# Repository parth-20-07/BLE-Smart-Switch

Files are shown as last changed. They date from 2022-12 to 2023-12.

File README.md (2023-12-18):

<!-- omit from toc -->
# BLE Smart Switch

**Table of Contents**

- [Why BLE Smart Switch is needed?](#why-ble-smart-switch-is-needed)
- [Features of our Smart Switch](#features-of-our-smart-switch)
- [How to use the device](#how-to-use-the-device)
- [Schematic Design](#schematic-design)
- [PCB Design](#pcb-design)
- [Rendered Images](#rendered-images)
- [Design Details](#design-details)

# Why BLE Smart Switch is needed?

The BLE Smart Switch provides convenient control over electrical sockets through Bluetooth technology. It enables users to manage home appliances remotely, ensuring energy efficiency and enhanced home automation.

# Features of our Smart Switch

- Control up to 2 sockets remotely.
- Schedule socket activation/deactivation.
- Real-time monitoring and control through a BLE app.
- Easy-to-use interface for hassle-free operation.
- Compact and modern design, suitable for various environments.

# How to use the device

1. Connect the device to the sockets you wish to control.
2. Pair the device with the BLE app.
3. Use the app to set schedules or control sockets manually.

# Schematic Design

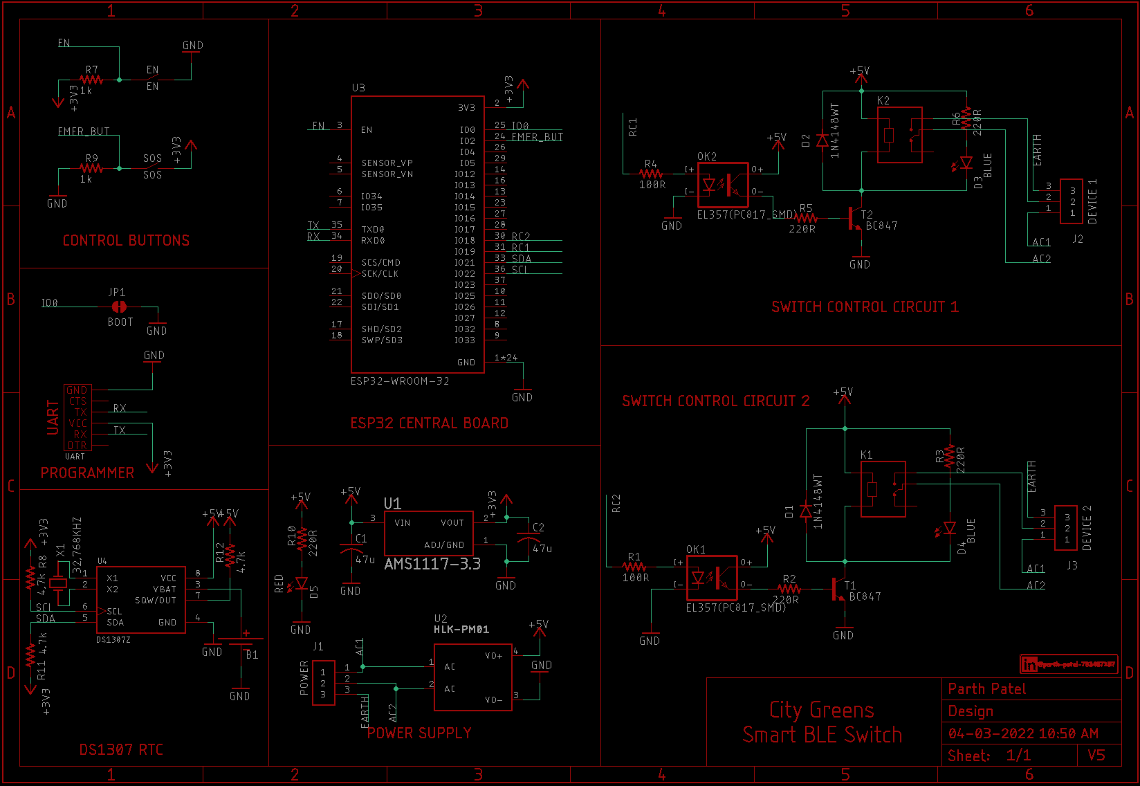
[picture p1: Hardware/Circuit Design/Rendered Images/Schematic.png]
schematic-1


# PCB Design

**Top View**

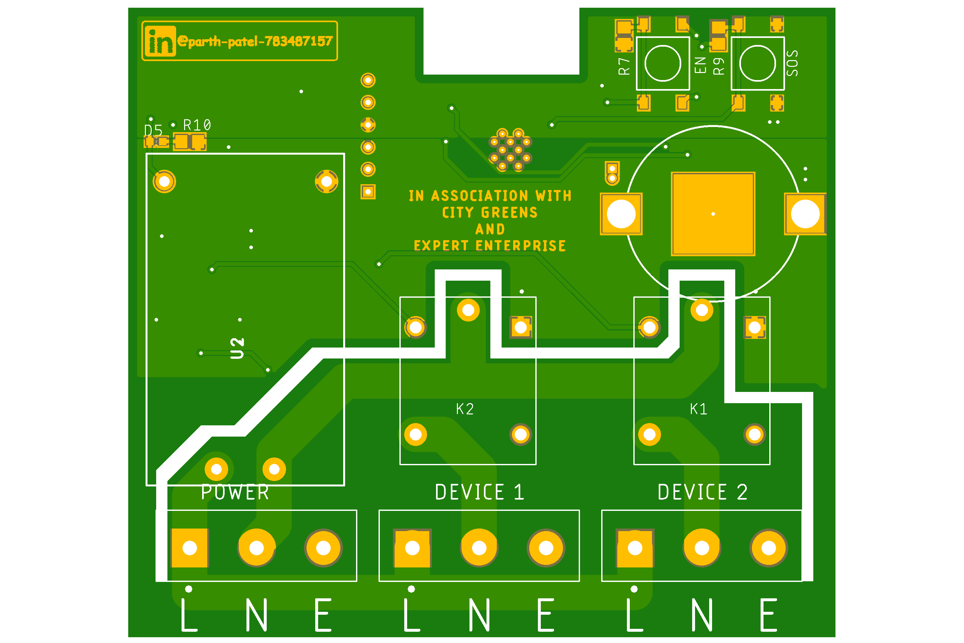
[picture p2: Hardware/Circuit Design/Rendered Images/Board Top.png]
pcb-top


**Bottom View**

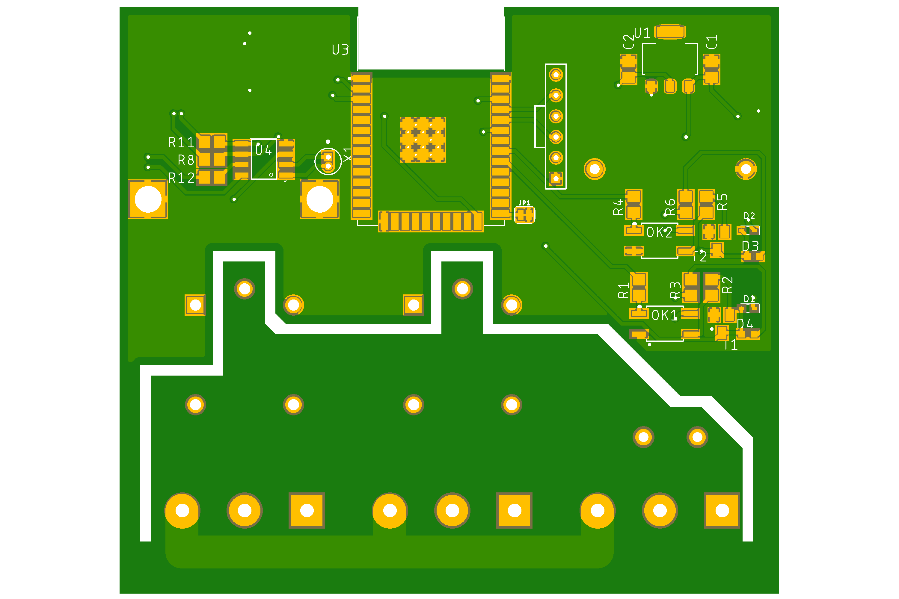
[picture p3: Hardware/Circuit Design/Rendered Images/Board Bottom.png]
pcb-bottom


# Rendered Images

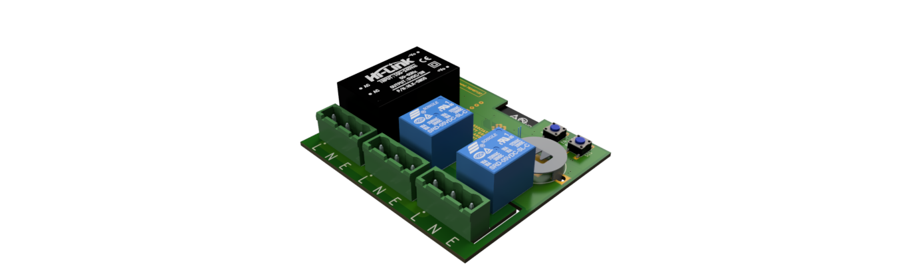
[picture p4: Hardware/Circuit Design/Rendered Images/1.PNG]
render-1


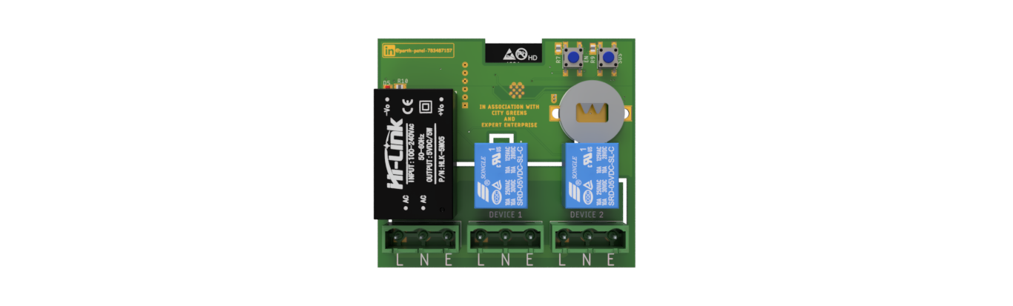
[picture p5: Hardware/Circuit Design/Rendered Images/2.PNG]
render-2


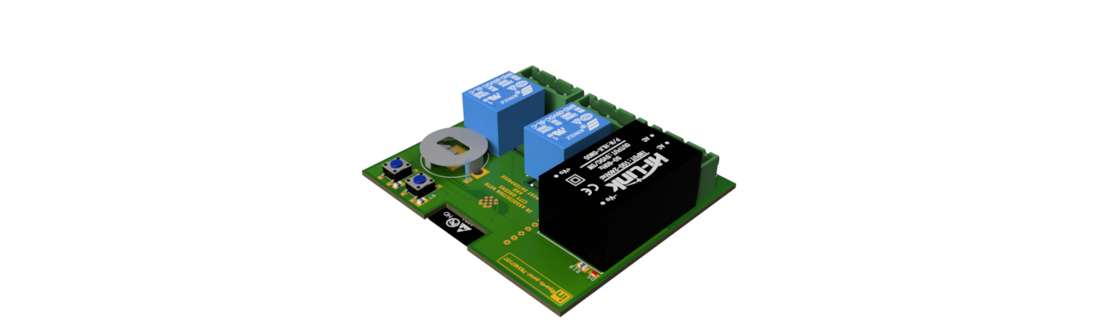
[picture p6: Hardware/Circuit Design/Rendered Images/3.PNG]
render-3


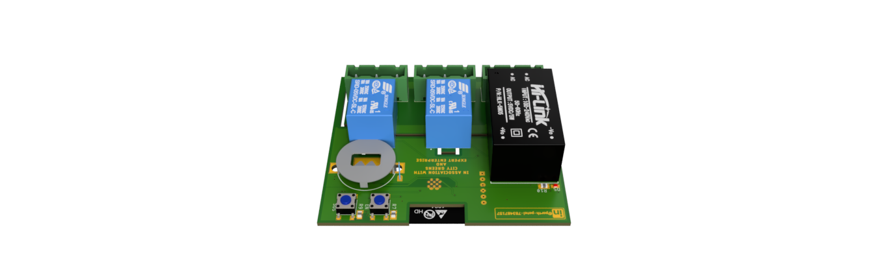
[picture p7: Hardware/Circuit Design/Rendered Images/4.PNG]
render-4


# Design Details

- Designed for: Ecologic Private Ltd.
- Designed by: [Parth Patel](mailto:parth.pmech@gmail.com)

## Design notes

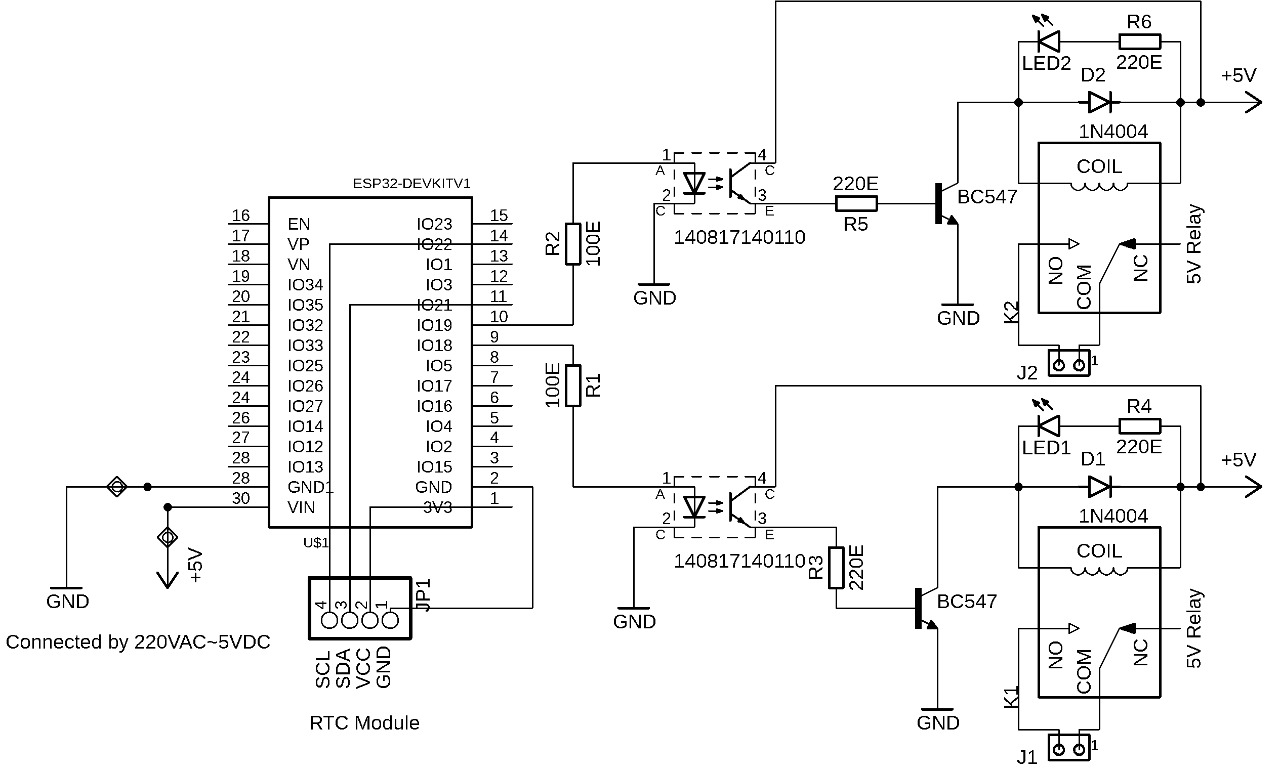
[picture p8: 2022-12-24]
Resources/Schematic Reference.jpg

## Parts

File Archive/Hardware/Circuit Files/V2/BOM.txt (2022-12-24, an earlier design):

TACTILE_SWITCH_SMD_4.5MM (Version 1): https://www.sunrom.com/p/smd-tactile-switch-45x45x38mm
0805 RESISTORS: https://www.sunrom.com/c/resistors?s_47%5B%5D=0805+%282012+metric%29
AMS1117-3.3: https://www.sunrom.com/p/ams1117-33-sot223
FUSE: https://www.sunrom.com/p/t63a-250v-rectangular-fuse
OPTOCOUPLER: https://www.sunrom.com/p/pc817-low-voltage-high-density-optocoupler
NPN: https://www.sunrom.com/p/bc847-npn-45v-100ma-sot23
Diode: https://www.sunrom.com/p/1n4148---1n4148wt---smd---sod523-0603
RED LED: https://www.sunrom.com/p/red-smd-led-0603
BLUE LED: https://www.sunrom.com/p/blue-smd-led-0603

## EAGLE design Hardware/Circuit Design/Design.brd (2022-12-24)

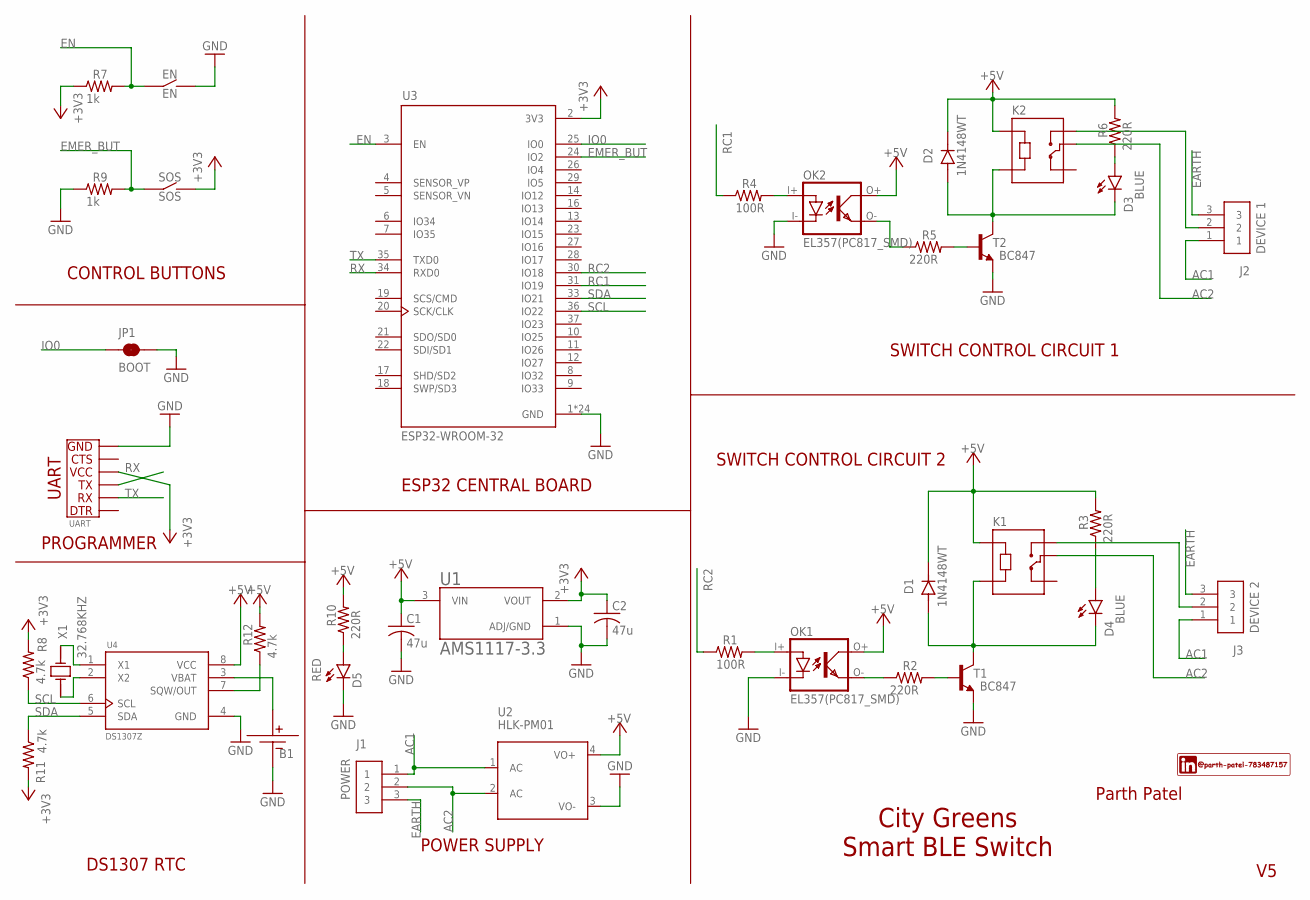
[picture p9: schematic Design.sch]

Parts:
B1: CR3032-METAL; CR2032-METAL
C1, C2: 47u; C0805
D1, D2: 1N4148WT; SODFL1608X70N
D3, D4: BLUE; CHIP-LED0603
D5: RED; CHIP-LED0603
EN: EN; SMD-4.5X4.5-TACTILE-PUSH-BUTTON
J1: POWER; TERMINALBLOCK_PLUGGABLE-3-7.62MM
J2: DEVICE 1; TERMINALBLOCK_PLUGGABLE-3-7.62MM
J3: DEVICE 2; TERMINALBLOCK_PLUGGABLE-3-7.62MM
JP1: BOOT; SMT-JUMPER_2_NC_TRACE_SILK
K1, K2: SRD-05VDC-SL-C; RELAY_SRD-05VDC-SL-C
OK1, OK2: EL357(PC817_SMD); SOP254P715X240-4N
R1, R4: 100R; R0805
R2, R3, R5, R6, R10: 220R; R0805
R7, R9: 1k; R0805
R8, R11, R12: 4.7k; R0805
SOS: SOS; SMD-4.5X4.5-TACTILE-PUSH-BUTTON
T1, T2: BC847; SOT23
U1: AMS1117-3.3; SOT229P700X180-4N
U2: HLK-PM01
U3: ESP32-WROOM-32; MODULE_ESP32-WROOM-32
U4: DS1307Z; SOIC127P600X175-8N
UART: UART
X1: 32.768KHZ; XTAL_AB38T-32.768KHZ

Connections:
+3V3: C2.1, R7.1, R8.2, R11.2, SOS.2.1 (S2), SOS.2.2 (S2), U1.2 (VOUT), U3.2 (3V3), UART.VCC
+5V: C1.1, D1.D+, D2.D+, K1.A1, K2.A1, OK1.O+, OK2.O+, R3.2, R6.2, R10.2, R12.2, U1.3 (VIN), U2.4 (VO+), U4.8 (VCC)
AC1: J1.1, J2.1, J3.1, U2.1 (AC)
AC2: J1.2, K1.COM, K2.COM, U2.2 (AC)
EARTH: J1.3, J2.3, J3.3
EMER_BUT: R9.2, SOS.1.1 (S1), SOS.1.2 (S1), U3.24 (IO2)
EN: EN.1.1 (S1), EN.1.2 (S1), R7.2, U3.3 (EN)
GND: B1.-VE1 (-VE), B1.-VE2 (-VE), C1.2, C2.2, D5.C, EN.2.1 (S2), EN.2.2 (S2), JP1.2, OK1.I-, OK2.I-, R9.1, T1.2 (E), T2.2 (E), U1.1 (ADJ/GND), U2.3 (VO-), U3.1 (GND), U3.15 (GND), U3.38 (GND), U3.39_1 (GND), U3.39_2 (GND), U3.39_3 (GND), U3.39_4 (GND), U3.39_5 (GND), U3.39_6 (GND), U3.39_7 (GND), U3.39_8 (GND), U3.39_9 (GND), U3.39_10 (GND), U3.39_11 (GND), U3.39_12 (GND), U3.39_13 (GND), U3.39_14 (GND), U3.39_15 (GND), U3.39_16 (GND), U3.39_17 (GND), U3.39_18 (GND), U3.39_19 (GND), U3.39_20 (GND), U3.39_21 (GND), U4.4 (GND), UART.GND
IO0: JP1.1, U3.25 (IO0)
unnamed: B1.+VE, U4.3 (VBAT)
unnamed: OK1.O-, R2.1
unnamed: OK1.I+, R1.2
unnamed: R2.2, T1.1 (B)
unnamed: R12.1, U4.7 (SQW/OUT)
unnamed: D1.D-, D4.C, K1.A2, T1.3 (C)
unnamed: D4.A, R3.1
unnamed: J3.2, K1.NO
unnamed: OK2.I+, R4.2
unnamed: OK2.O-, R5.1
unnamed: R5.2, T2.1 (B)
unnamed: D2.D-, D3.C, K2.A2, T2.3 (C)
unnamed: D3.A, R6.1
unnamed: U4.2 (X2), X1.1
unnamed: J2.2, K2.NO
unnamed: U4.1 (X1), X1.2
unnamed: D5.A, R10.1
RC1: R4.1, U3.31 (IO19)
RC2: R1.1, U3.30 (IO18)
RX: U3.34 (RXD0), UART.TX
SCL: R8.1, U3.36 (IO22), U4.6 (SCL)
SDA: R11.1, U3.33 (IO21), U4.5 (SDA)
TX: U3.35 (TXD0), UART.RX

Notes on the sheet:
City Greens Smart BLE Switch
Parth Patel
ESP32 CENTRAL BOARD
DS1307 RTC
POWER SUPPLY
SWITCH CONTROL CIRCUIT 1
SWITCH CONTROL CIRCUIT 2
CONTROL BUTTONS
PROGRAMMER

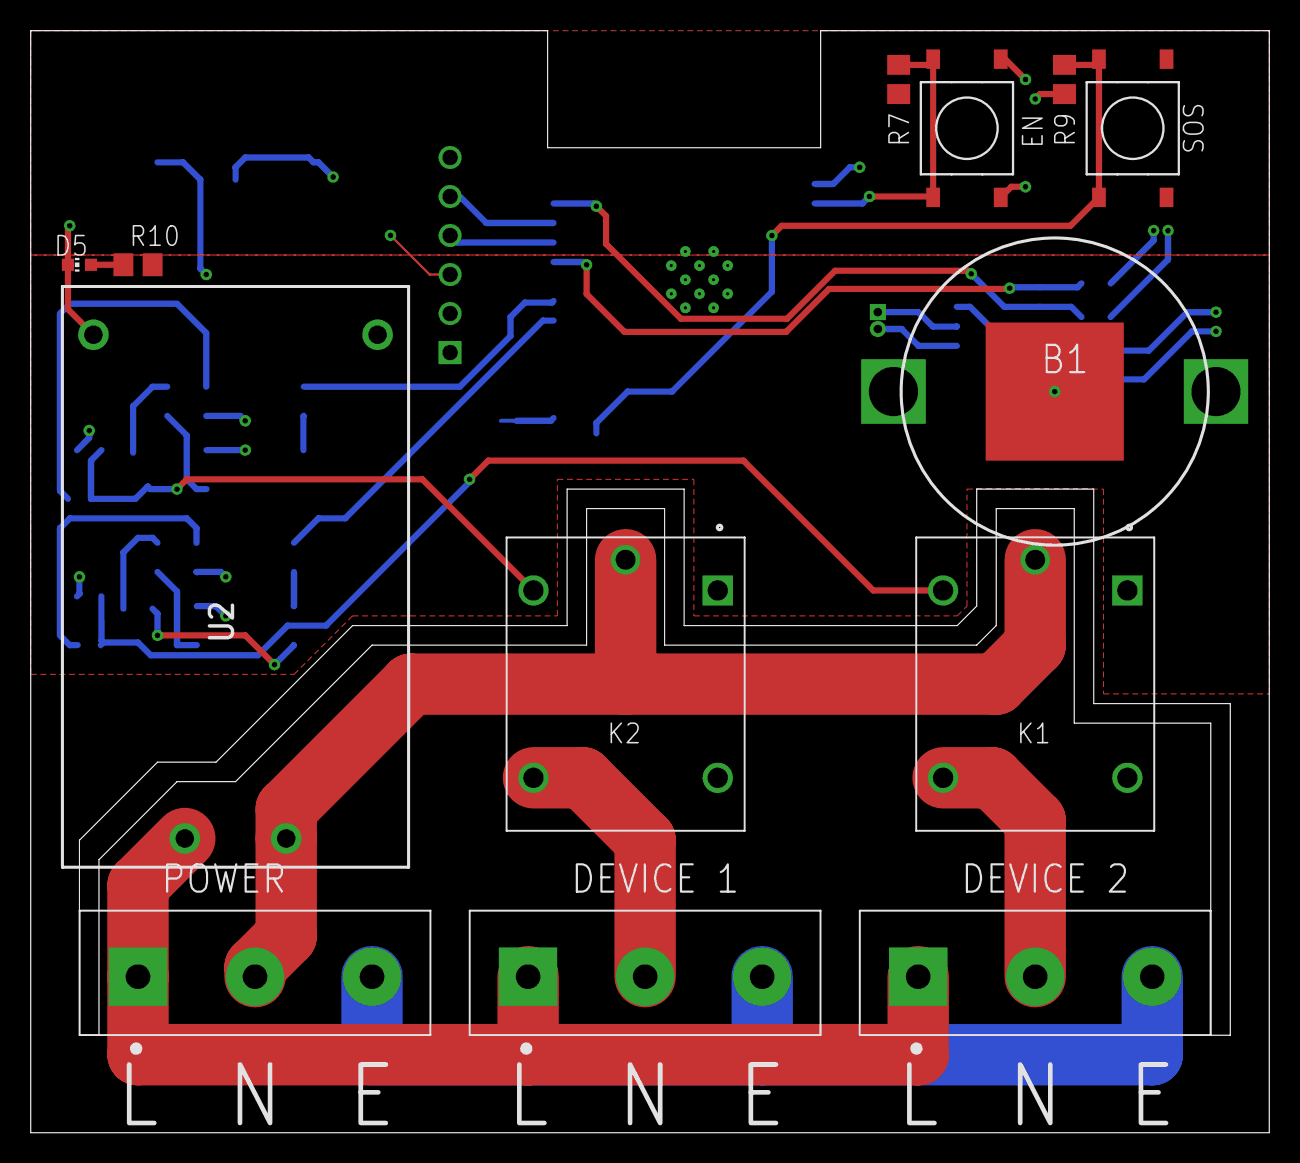
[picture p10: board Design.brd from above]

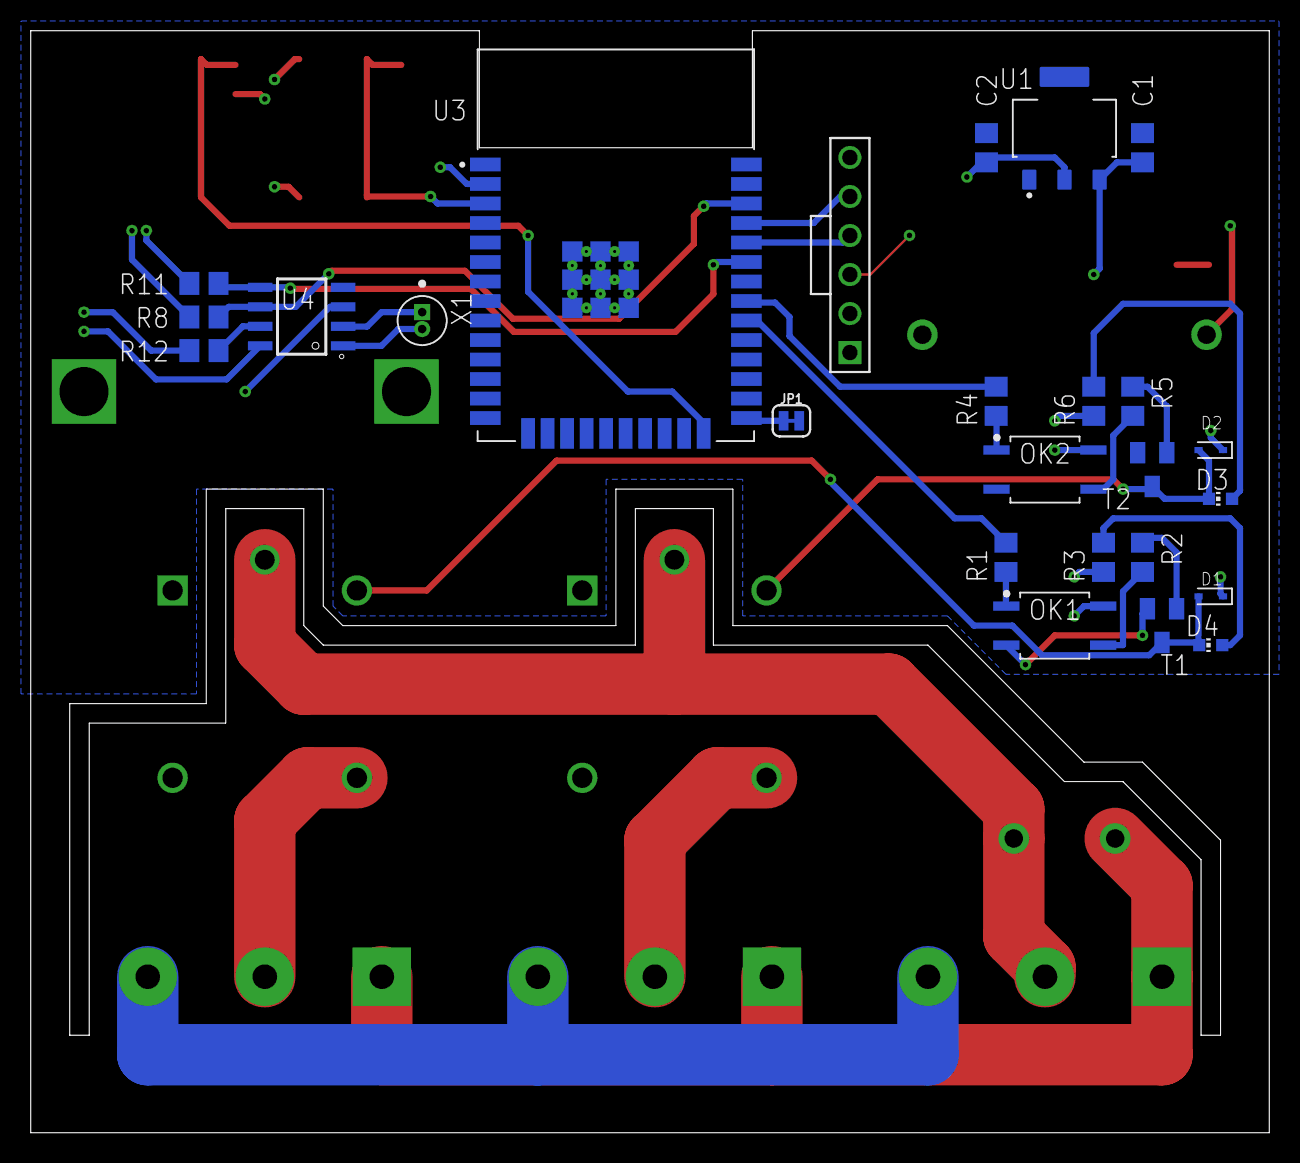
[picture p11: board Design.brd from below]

Board: 2 copper layers, 80.6 x 71.8 mm, 38 parts (25 on the bottom side), 32 nets.

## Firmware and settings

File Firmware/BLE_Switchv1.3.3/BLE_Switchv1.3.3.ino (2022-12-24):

#include <Arduino.h>
#include <nvs_flash.h>

#include "soc/timer_group_struct.h"
#include "soc/timer_group_reg.h"

#define PIN_SCL 22
#define PIN_SDA 21
//-----------------Flags to control state of interfaces for various switching mode-------------
bool app1Flg = true;
bool app2Flg = true;
bool sosFlag = false;
bool tFlag = false; // Flag to indicate Switch Mode command
bool prev_tFlag = false;
bool app1State;
bool app2State;
bool autoMode;
//---------------------------Data Point Storage Variables--------------------------------------
const char *path = "/switchData.txt";
char timeStamp[17];
char msg[23];
int tBytes = 0;
int uBytes = 0;
bool wFlag = false;
unsigned int dCount = 0;
//-----------------------------Variables for Switch Mode---------------------------------------
unsigned int min1 = 0; // Count minutes needed to periodically switch interface 1
unsigned int min2 = 0; // Count minutes needed to periodically switch interface 2
uint8_t rmin = 0;      // Minute variable needed for Timeframe switch mode operation
uint8_t rhr = 0;       // Hour variable needed for Timeframe switch mode operation

bool week[7] = {false, false, false, false, false, false, false};
byte cur_day = 7;
byte curr_zone = 5, prev_zone = 0;
bool zoneChg = false;
unsigned int app1ON, app1OFF, app2ON, app2OFF;
char sch_buff[3];
byte sch;
byte frame_App1[18][4];
byte frame_App2[18][4];
char rtcDay[7][10] = {"Sunday", "Monday", "Tuesday", "Wednesday", "Thursday", "Friday", "Saturday"};
byte App1Sch;
byte App2Sch;
byte b = 0;
byte diff = 0;

void defaultState()
{
  // Configure the Prescaler at 80 the quarter of the ESP32 is cadence at 80Mhz
  // 80000000 / 80 = 1000000 tics / seconde
  timer = timerBegin(0, 80, true); // true - count up; false - count down
  timerAttachInterrupt(timer, &onTime, true);
  timerAlarmWrite(timer, 60 * 1000000, true);
  timerAlarmDisable(timer);

  tFlag = false;
  pref.putBool("prev_tFlag", false);

  smode = 'M';
  initFlg = false;

  app[0].ID[0] = '0';
  app[0].ID[1] = '1';
  app[0].ID[2] = NULL;
  app[1].ID[0] = '0';
  app[1].ID[1] = '2';
  app[1].ID[2] = NULL;

  app[0].prev_state = 0;
  app[0].curr_state = 0;
  app[1].prev_state = 0;
  app[1].curr_state = 0;

  app[0].val[0].mData = 0;
  app[1].val[0].mData = 0;

  for (int k = 0; k < 4; k++)
  {
    app[0].val[k].onMin = 0;
    app[0].val[k].offMin = 0;
    app[1].val[k].onMin = 0;
    app[1].val[k].offMin = 0;
  }

  for (i = 0; i < 4; i++)
  {
    app[0].val[0].tON[i] = 0;
    app[1].val[0].tON[i] = 0;
  }

  for (i = 0; i < 18; i++)
  {
    for (int k = 0; k < 4; k++)
    {
      frame_App1[i][k] = 0;
      frame_App2[i][k] = 0;
    }
  }
  sch = 0;
  App1Sch = 0;
  App2Sch = 0;
  prev_zone = 0;
  autoMode = 0;
  zoneChg = false;

  // Timeframe
  for (i = 0; i < 7; i++)
    week[i] = 0;
  App1Sch = 0;
  App2Sch = 0;
  for (i = 0; i < 18; i++)
  {
    for (int j = 0; j < 4; j++)
      frame_App1[i][j] = 0;
  }

  for (i = 0; i < 18; i++)
  {
    for (int j = 0; j < 4; j++)
      frame_App2[i][j] = 0;
  }
  writeFile("Dy/M/Y,H:M,App1,App2\r\n");
}

void savedData()
{
  // Configure the Prescaler at 80 the quarter of the ESP32 is cadence at 80Mhz
  // 80000000 / 80 = 1000000 tics / seconde
  timer = timerBegin(0, 80, true); // true - count up; false - count down
  timerAttachInterrupt(timer, &onTime, true);
  timerAlarmWrite(timer, 60 * 1000000, true); // 1 minute Timer
  timerAlarmDisable(timer);

  smode = pref.getChar("mode", 0);

  app[0].ID[0] = '0';
  app[0].ID[1] = '1';
  app[0].ID[2] = NULL;
  app[1].ID[0] = '0';
  app[1].ID[1] = '2';
  app[1].ID[2] = NULL;

  app[0].prev_state = pref.getBool("pState1", 0);
  app[0].curr_state = 0;
  app[1].prev_state = pref.getBool("pState2", 0);
  app[1].curr_state = 0;
  // Manual Mode
  app[0].val[0].mData = pref.getBool("man1", 0);
  app[1].val[0].mData = pref.getBool("man2", 0);
  // Period Mode
  app[0].val[0].onMin = pref.getInt("z1A1ON", 0);
  app[0].val[0].offMin = pref.getInt("z1A1OFF", 0);
  app[0].val[1].onMin = pref.getInt("z2A1ON", 0);
  app[0].val[1].offMin = pref.getInt("z2A1OFF", 0);
  app[0].val[2].onMin = pref.getInt("z3A1ON", 0);
  app[0].val[2].offMin = pref.getInt("z3A1OFF", 0);
  app[0].val[3].onMin = pref.getInt("z4A1ON", 0);
  app[0].val[3].offMin = pref.getInt("z4A1OFF", 0);

  app[1].val[0].onMin = pref.getInt("z1A2ON", 0);
  app[1].val[0].offMin = pref.getInt("z1A2OFF", 0);
  app[1].val[1].onMin = pref.getInt("z2A2ON", 0);
  app[1].val[1].offMin = pref.getInt("z2A2OFF", 0);
  app[1].val[2].onMin = pref.getInt("z3A2ON", 0);
  app[1].val[2].offMin = pref.getInt("z3A2OFF", 0);
  app[1].val[3].onMin = pref.getInt("z4A2ON", 0);
  app[1].val[3].offMin = pref.getInt("z4A2OFF", 0);

  min1 = pref.getUInt("m1", 0);
  min2 = pref.getUInt("m2", 0);

  // Timeframe
  pref.getBytes("Week", week, 7);
  App1Sch = pref.getInt("A1Sch", 0);
  App2Sch = pref.getInt("A2Sch", 0);
  pref.getBytes("TFA1", frame_App1, 72);
  pref.getBytes("TFA2", frame_App1, 72);

  autoMode = pref.getBool("auto", 0);
  if (autoMode == 1)
  {
    tFlag = true;
    Serial.println("[AUTO MODE] ON");
    pCharacteristic->setValue("[AUTO MODE] ON");
    pCharacteristic->notify();
    if ((smode == 'P') || (smode == 'T'))
      timerAlarmEnable(timer);
  }
  else
  {
    tFlag = false;
    Serial.println("[AUTO MODE] OFF");
    pCharacteristic->setValue("[AUTO MODE] OFF");
    pCharacteristic->notify();
  }
}

void setup()
{
  Serial.begin(115200);
  // BLE Configuration
  bleConf();
  initFlg = pref.getBool("svFlg", 0);
  if (initFlg)
  {
    Serial.println("Loading saved configuration...");
    savedData();
  }
  else
  {
    Serial.println("Loading default configuration...");
    defaultState();
  }

  pref.end();

  pinMode(AP1_pin, OUTPUT);
  pinMode(AP2_pin, OUTPUT);
  pinMode(SOS_Button, INPUT);
  digitalWrite(AP1_pin, LOW);
  digitalWrite(AP2_pin, LOW);

  while ((!rtc.begin()) && i < 5)
  {
    Serial.println("Couldn't find RTC");
    pCharacteristic->setValue("[Error] RTC not found.");
    pCharacteristic->notify();
    i++;
  }
  rtc.adjust(DateTime(__DATE__, __TIME__));
}

void bleConf()
{
  Serial.println("Starting BLE Switch!");

  BLEDevice::init("BLE_Switch");

  pServer = BLEDevice::createServer();
  pServer->setCallbacks(new MyServCallbacks());

  BLEService *pService = pServer->createService(SERVICE_UUID);

  pCharacteristic = pService->createCharacteristic(
      CHARACTERISTIC_UUID,
      BLECharacteristic::PROPERTY_READ | BLECharacteristic::PROPERTY_NOTIFY | BLECharacteristic::PROPERTY_WRITE);
  pCharacteristic->addDescriptor(new BLE2902());
  pCharacteristic->setCallbacks(new MyCallbacks());
  pService->start();

  // BLEAdvertising *pAdvertising = pServer->getAdvertising();  // this still is working for backward compatibility
  BLEAdvertising *pAdvertising = BLEDevice::getAdvertising();
  pAdvertising->addServiceUUID(SERVICE_UUID);
  pAdvertising->setScanResponse(false);
  pAdvertising->setMinPreferred(0x00); // functions that help with iPhone connections issue 0x06
  // pAdvertising->setMinPreferred(0x12);
  BLEDevice::startAdvertising();
  Serial.println("Characteristic defined! Now you can read it in your phone!");
}

void stateChg()
{
  rtcFunc();
  strcpy(msg, timeStamp);
  strcat(msg, ",");
  if (app[0].curr_state)
    strcat(msg, "1");
  else
    strcat(msg, "0");
  strcat(msg, ",");
  if (app[1].curr_state)
    strcat(msg, "1");
  else
    strcat(msg, "0");
  strcat(msg, "\r\n");
  appendFile(msg);
  /*pref.begin("store",false);
  pref.putBool("pState1", app[0].prev_state);
  //pref.putBool("cState1", app[0].curr_state);
  pref.putBool("pState2", app[1].prev_state);
  //pref.putBool("cState2", app[1].curr_state);
  pref.end();*/
}

void feedWDT()
{
  TIMERG0.wdt_wprotect = TIMG_WDT_WKEY_VALUE;
  TIMERG0.wdt_feed = 1;
  TIMERG0.wdt_wprotect = 0;
}

void periodMode()
{
  if (timerFlg)
  {
    // Comment out enter / exit to deactivate the critical section
    portENTER_CRITICAL(&timerMux);
    timerFlg = false;
    portEXIT_CRITICAL(&timerMux);
    rtcFunc();

    // Get ON and OFF time for respective timezone
    if (zoneChg)
    {
      switch (curr_zone)
      {
      case 1:
        if (app[0].val[0].onMin > 0 || app[0].val[0].offMin > 0 || app[1].val[0].onMin > 0 || app[1].val[0].offMin > 0)
        {
          min1 = 0;
          min2 = 0;
          app1ON = app[0].val[0].onMin;
          app1OFF = app[0].val[0].offMin;
          app2ON = app[1].val[0].onMin;
          app2OFF = app[1].val[0].offMin;
          Serial.println("TimeZone 1 Periodic Mode Set");
          pFlag = true;
        }
        else
          pFlag = false;
        break;
      case 2:
        if (app[0].val[1].onMin > 0 || app[0].val[1].offMin > 0 || app[1].val[1].onMin > 0 || app[1].val[1].offMin > 0)
        {
          min1 = 0;
          min2 = 0;
          app1ON = app[0].val[1].onMin;
          app1OFF = app[0].val[1].offMin;
          app2ON = app[1].val[1].onMin;
          app2OFF = app[1].val[1].offMin;
          pFlag = true;
          Serial.println("TimeZone 2 Periodic Mode Set");
        }
        else
          pFlag = false;
        break;
      case 3:
        if (app[0].val[2].onMin > 0 || app[0].val[2].offMin > 0 || app[1].val[2].onMin > 0 || app[1].val[2].offMin > 0)
        {
          min1 = 0;
          min2 = 0;
          app1ON = app[0].val[2].onMin;
          app1OFF = app[0].val[2].offMin;
          app2ON = app[1].val[2].onMin;
          app2OFF = app[1].val[2].offMin;
          pFlag = true;
          Serial.println("TimeZone 3 Periodic Mode Set");
        }
        else
          pFlag = false;
        break;
      case 4:
        if (app[0].val[3].onMin > 0 || app[0].val[3].offMin > 0 || app[1].val[3].onMin > 0 || app[1].val[3].offMin > 0)
        {
          min1 = 0;
          min2 = 0;
          app1ON = app[0].val[3].onMin;
          app1OFF = app[0].val[3].offMin;
          app2ON = app[1].val[3].onMin;
          app2OFF = app[1].val[3].offMin;
          pFlag = true;
          Serial.println("TimeZone 4 Periodic Mode Set");
        }
        else
          pFlag = false;
        break;
      }
      if (!pFlag)
      {
        Serial.print("No time setting for Timezone: ");
        Serial.println(curr_zone);
        app1ON = 0;
        app1OFF = 0;
        app2ON = 0;
        app2OFF = 0;
      }

      Serial.print("Appliance 1 ON TIME: ");
      Serial.println(app1ON);
      Serial.print("Appliance 1 OFF TIME: ");
      Serial.println(app1OFF);
      Serial.print("Appliance 2 ON TIME: ");
      Serial.println(app2ON);
      Serial.print("Appliance 2 OFF TIME: ");
      Serial.println(app2OFF);
    }
    min1++;
    min2++;

    pref.begin("store", false);
    pref.putUInt("m1", min1);
    pref.putUInt("m2", min2);
    pref.end();

    Serial.print("Period 1: ");
    Serial.println(min1);
    Serial.print("Period 2: ");
    Serial.println(min2);

    if (week[cur_day] && pFlag)
    {
      // Setting for Appliance 1
      if (min1 <= app1ON)
      {
        digitalWrite(AP1_pin, HIGH);
        Serial.println("Interface 1: HIGH");
        app[0].curr_state = 1;
      }
      else if (min1 > app1ON && min1 <= (app1ON + app1OFF))
      {
        digitalWrite(AP1_pin, LOW);
        Serial.println("Interface 1: LOW");
        app[0].curr_state = 0;
      }
      else if (app1ON != 0)
      {
        digitalWrite(AP1_pin, HIGH);
        Serial.println("Interface 1: HIGH");
        app[0].curr_state = 1;
        min1 = 1;
      }

      // Setting for Appliance 2
      if (min2 <= app2ON)
      {
        digitalWrite(AP2_pin, HIGH);
        Serial.println("Interface 2: HIGH");
        app[1].curr_state = 1;
      }
      else if (min2 > app2ON && min2 <= (app2ON + app2OFF))
      {
        digitalWrite(AP2_pin, LOW);
        Serial.println("Interface 2: LOW");
        app[1].curr_state = 0;
      }
      else if (app2OFF != 0)
      {
        digitalWrite(AP2_pin, HIGH);
        Serial.println("Interface 2: HIGH");
        app[1].curr_state = 1;
        min2 = 1;
      }
    }
    else
    {
      digitalWrite(AP1_pin, LOW);
      digitalWrite(AP2_pin, LOW);
      Serial.println("Interface 1: LOW");
      Serial.println("Interface 2: LOW");
    }
  }
}

void timeFrameMode()
{
  if (timerFlg)
  {
    // Comment out enter / exit to deactivate the critical section
    portENTER_CRITICAL(&timerMux);
    timerFlg = false;
    portEXIT_CRITICAL(&timerMux);
    rtcFunc();
    // Check Appliance 1 schedules
    if (week[cur_day] && App1Sch > 0)
    {
      for (int b = 0; b < App1Sch; b++)
      {
        diff = frame_App1[b][2] - frame_App1[b][0];
        if (diff > 0)
        {
          if (rhr == frame_App1[b][0])
          {
            if ((rhr >= frame_App1[b][0] && rmin >= frame_App1[b][1]) && (rhr <= frame_App1[b][0] && rmin <= 59))
            {
              app[0].curr_state = 1;
              break;
            }
            else
              app[0].curr_state = 0;
          }
          else if (rhr == frame_App1[b][2])
          {
            if ((rhr >= frame_App1[b][2] && rmin >= 0) && (rhr <= frame_App1[b][2] && rmin <= frame_App1[b][3]))
            {
              app[0].curr_state = 1;
              break;
            }
            else
              app[0].curr_state = 1;
          }
          else
          {
            for (int l = 1; l < diff; l++)
            {
              if ((rhr >= (frame_App1[b][0] + l) && rmin >= 0) && (rhr <= (frame_App1[b][0] + l) && rmin <= 59))
              {
                app[0].curr_state = 1;
                break;
              }
              else
                app[0].curr_state = 0;
            }
          }
        }
        else
        {
          if ((rhr >= frame_App1[b][0] && rmin >= frame_App1[b][1]) && (rhr <= frame_App1[b][2] && rmin < frame_App1[b][3]))
          {
            app[0].curr_state = 1;
            break;
          }
          else
            app[0].curr_state = 0;
        }
      }
    }
    else
    {
      app[0].curr_state = 0;
    }
    // Check Appliance 2 schedules
    if (week[cur_day] && App2Sch > 0)
    {
      for (int b = 0; b < App2Sch; b++)
      {
        diff = frame_App2[b][2] - frame_App2[b][0];
        if (diff > 0)
        {
          if (rhr == frame_App2[b][0])
          {
            if ((rhr >= frame_App2[b][0] && rmin >= frame_App2[b][1]) && (rhr <= frame_App2[b][0] && rmin <= 59))
            {
              app[1].curr_state = 1;
              break;
            }
            else
              app[1].curr_state = 0;
          }
          else if (rhr == frame_App2[b][2])
          {
            if ((rhr >= frame_App2[b][2] && rmin >= 0) && (rhr <= frame_App2[b][2] && rmin < frame_App2[b][3]))
            {
              app[1].curr_state = 1;
              break;
            }
            else
              app[1].curr_state = 0;
          }
          else
          {
            for (int l = 1; l < diff; l++)
            {
              if ((rhr >= (frame_App2[b][0] + l) && rmin >= 0) && (rhr <= (frame_App2[b][0] + l) && rmin <= 59))
              {
                app[1].curr_state = 1;
                break;
              }
              else
                app[1].curr_state = 0;
            }
          }
        }
        else
        {
          if ((rhr >= frame_App2[b][0] && rmin >= frame_App2[b][1]) && (rhr <= frame_App2[b][2] && rmin < frame_App2[b][3]))
          {
            app[1].curr_state = 1;
            break;
          }
          else
            app[1].curr_state = 0;
        }
      }
    }
    else
    {
      app[1].curr_state = 0;
    }

    if (app[0].curr_state == 1)
    {
      Serial.println("Appliance 1: HIGH");
      digitalWrite(AP1_pin, HIGH);
    }
    else
    {
      Serial.println("Appliance 1: LOW");
      digitalWrite(AP1_pin, LOW);
    }

    if (app[1].curr_state == 1)
    {
      Serial.println("Appliance 2: HIGH");
      digitalWrite(AP2_pin, HIGH);
    }
    else
    {
      Serial.println("Appliance 2: LOW");
      digitalWrite(AP2_pin, LOW);
    }
  }
}

void manualMode()
{
  if (app1Flg)
  {
    if (app[0].val[0].mData == 1)
    {
      Serial.println("Appliance 1: HIGH");
      digitalWrite(AP1_pin, HIGH);
    }
    else
    {
      Serial.println("Appliance 1: LOW");
      digitalWrite(AP1_pin, LOW);
    }
    app[0].curr_state = app[0].val[0].mData;
    app1Flg = false;
  }
  if (app2Flg)
  {
    if (app[1].val[0].mData == 1)
    {
      Serial.println("Appliance 2: HIGH");
      digitalWrite(AP2_pin, HIGH);
    }
    else
    {
      Serial.println("Appliance 2: LOW");
      digitalWrite(AP2_pin, LOW);
    }
    app[1].curr_state = app[1].val[0].mData;
    app2Flg = false;
  }
}

void loop()
{
  bleDevice();
  feedWDT();
  vTaskDelay(5 / portTICK_PERIOD_MS);
  // emergencyCheck();
  if (!tFlag)
    timerAlarmDisable(timer);
  else if (!cmdF && tFlag)
  {
    if (smode == 'M')
      manualMode();
    else if (smode == 'P')
      periodMode();
    else if (smode == 'T')
      timeFrameMode();
  }

  if ((app[0].prev_state != app[0].curr_state) || (app[1].prev_state != app[1].curr_state))
    stateChg();

  pref.begin("store", false);
  pref.putBool("pState1", app[0].curr_state);
  pref.putBool("pState2", app[1].curr_state);
  app[0].prev_state = pref.getBool("pState1", 0);
  app[1].prev_state = pref.getBool("pState2", 0);
  pref.end();

  delay(500);
}

void swApp()
{
  app1Flg = true;
  app2Flg = true;
  min1 = 0;
  min2 = 0;
  switch (smode)
  {
  case 'M':
    Serial.println("------------");
    Serial.println("MANUAL MODE:");
    Serial.println("------------");
    pCharacteristic->setValue("[MODE] Manual");
    pCharacteristic->notify();
    break;
  case 'P':
    Serial.println("------------");
    Serial.println("PERIOD MODE:");
    Serial.println("------------");
    pCharacteristic->setValue("[MODE] Periodic");
    pCharacteristic->notify();

    app[0].curr_state = 0;
    app[1].curr_state = 0;

    // Interface 1
    digitalWrite(AP1_pin, LOW);
    Serial.println("Interface 1: LOW");
    // Interface 2
    digitalWrite(AP2_pin, LOW);
    Serial.println("Interface 2: LOW");
    timerAlarmEnable(timer);
    break;
  case 'T':
    Serial.println("------------");
    Serial.println("TIMEFRAME MODE:");
    Serial.println("------------");
    pCharacteristic->setValue("[MODE] Timeframe");
    pCharacteristic->notify();
    app[0].curr_state = 0;
    app[1].curr_state = 0;
    // Interface 1
    digitalWrite(AP1_pin, LOW);
    // Serial.println("Interface 1: LOW");
    // Interface 2
    digitalWrite(AP2_pin, LOW);
    // Serial.println("Interface 2: LOW");
    timerAlarmEnable(timer);
    break;
  }
}

void rtcFunc()
{
  DateTime now = rtc.now();
  Serial.print(now.year(), DEC);
  Serial.print('/');
  Serial.print(now.month(), DEC);
  Serial.print('/');
  Serial.print(now.day(), DEC);
  Serial.print(" ");
  cur_day = now.dayOfTheWeek();
  Serial.println(cur_day);
  rhr = now.hour();
  Serial.print(rhr);
  Serial.print(':');
  rmin = now.minute();
  Serial.println(rmin);
  sprintf(timeStamp, "%02d/%02d/%04d,%02d:%02d", now.day(), now.month(), now.year(), now.hour(), now.minute());
  getTimeZone();
}

void getTimeZone()
{
  /*TimeZone 1: 06:00 AM to 11:59 AM  (06:00 - 11:59)
    TimeZone 2: 12:00 PM to 05:59 PM  (12:00 - 17:59)
    TimeZone 3: 06:00 PM to 11:59 PM  (18:00 - 23:59)
    TimeZone 4: 12:00 AM to 05:59 AM  (00:00 - 05:59)
  */
  if (rhr >= 6 && (rhr <= 11 && rmin <= 59))
  {
    curr_zone = 1;
  }
  else if (rhr >= 12 && (rhr <= 17 && rmin <= 59))
  {
    curr_zone = 2;
  }
  else if (rhr >= 18 && (rhr <= 23 && rmin <= 59))
  {
    curr_zone = 3;
  }
  else if (rhr >= 00 && (rhr <= 5 && rmin <= 59))
  {
    curr_zone = 4;
  }
  if (prev_zone != curr_zone)
    zoneChg = true;
  else
    zoneChg = false;
  prev_zone = curr_zone;
}

void bleDevice()
{
  if (deviceConnected)
  {
    if (devCon)
    {
      swInfo();
      pCharacteristic->setValue("[BLE Switch] Ready");
      pCharacteristic->notify();
      devCon = false;
    }
  }
  if (!deviceConnected && oldDeviceConnected)
  {
    delay(500);
    // BLEDevice::startAdvertising();
    pServer->startAdvertising();
    Serial.println("Start Advertising again...");
    oldDeviceConnected = deviceConnected;
    devCon = true;
  }

  if (deviceConnected && !oldDeviceConnected)
  {
    oldDeviceConnected = deviceConnected;
  }
}

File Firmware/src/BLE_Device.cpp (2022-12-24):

#include "BLE_Device.h"

/* ------------------------ Adding Required Libraries ----------------------- */
#include <Arduino.h>
#include <BLEDevice.h>
#include <BLEUtils.h>
#include <BLEServer.h>
#include <BLE2902.h>
#include <Preferences.h>
#include "Timer.h"

// BLE Device Configuration
#define SERVICE_UUID "208fc8fc-64ed-4423-ba22-2230821ae406"
#define CHARACTERISTIC_UUID "e462c4e9-3704-4af8-9a20-446fa2eef1d0"
Preferences pref;

//--------------------Data Structure for Appliance Interface---------------------------------
typedef struct
{
    bool mData;          // Stores Manual Mode Value (0/1)
    unsigned int onMin;  // Stores ON time (in minutes) for Periodic Mode
    unsigned int offMin; // Stores OFF time (in minutes) for Periodic Mode
    uint8_t tON[4];      // Stores FROM-TO (in Hr:Min) time interval for Timeframe Mode
} Data;

typedef struct
{
    char ID[3];      // Stores Interface ID
    bool curr_state; // Stores Current state of interface
    bool prev_state; // Stores previous state of Interface
    Data val[4];
} Interface;
uint8_t nInterface = 2; // Number of available interfaces
Interface app[2];
char smode;      // Stores Interface Mode [Manual (M), Periodic (P), Timeframe (T)]
char delm = ','; // CSV format using comma as delimeter

//----------------------- BLE Communication protocol data structure----------------------------
BLEServer *pServer = NULL;
BLECharacteristic *pCharacteristic = NULL;
bool deviceConnected = false;
bool oldDeviceConnected = false;
bool devCon = true;
bool pFlag = false;

//---------------------------Commands from User through Mobile App-----------------------------
char cmdKey = 'X';
bool cmdF = false;   // Flag to indicate command received from mobile app
char App1onBuff[4];  // Buffer to store ON time for periodic/timeframe mode
char App1offBuff[4]; // Buffer to store OFF time for periodic/timeframe mode
char App2onBuff[4];
char App2offBuff[4];
char cmdBuff[4];
String sInfo = "";    // Stores device info such as no. of interfaces, its mode and state.
bool initFlg = false; // Flag variable for device on-start setup configuration
byte i = 0;

//---------------------- Callback function related to device connection------------------------
class MyServCallbacks : public BLEServerCallbacks
{
    void onConnect(BLEServer *pServer)
    {
        deviceConnected = true;
    }
    void onDisconnect(BLEServer *pServer)
    {
        deviceConnected = false;
    }
};
//-------------------Callback function for read/write charactersitic value---------------------
class MyCallbacks : public BLECharacteristicCallbacks
{
    void onWrite(BLECharacteristic *pCharacteristic)
    {
        std::string value = pCharacteristic->getValue();
        /*
         * Check for commands received from Mobile App
         *  Info command             : I swInfo()
         *  Switch command           : S swApp()
         *    Periodic               : P
         *    Timeframe              : T
         *    Manual                 : M             :
         *  Factory Reset command    : F
         *  Restart command          : R
         *  Data Sync command        : D
         *  Switch Resume command    : B
         *  Pause command            : P
         *  Auto mode                : A
         *  RTC Adjust command       : C
         */
        if (value.length() > 0)
        {
            pref.begin("store", false);
            cmdF = true;
            if ((smode == 'P') || (smode == 'T'))
                timerAlarmDisable(timer);
            char cmd[(value.length()) + 1];
            uint8_t cdelm = 0;
            i = 0;
            while (i <= value.length())
            {
                cmd[i] = value[i];
                i++;
            }
            cmd[i] = '\0';
            Serial.println("-----------");
            i = 0;
            //------------------------------------------------------//
            // Parsing CSV command data to extract useful information
            //------------------------------------------------------//
            if (cmd[i] == 'F' && cmd[i + 1] == '\0')
            { //[Factory Reset Command]
                cmdKey = 'F';
                Serial.println("Factory Reset Command"); // Command Format: {'F','\0'}
                nvs_flash_erase();                       // Erase Non-Voltage Storage (NVS) which stores state variables
                nvs_flash_init();
                deleteFile(); // Delete data point file stored in SPIFFS FileSystem
                ESP.restart();
            }
            else if (cmd[i] == 'I' && cmd[i + 1] == '\0') //[Switch Info Command]
            {                                             // Command Format: {'I', '\0'}
                cmdKey = 'I';
                Serial.println("Info Command");
                swInfo();
            }
            else if (cmd[i] == 'D' && cmd[i + 1] == '\0') //[Data Sync Command]
            {
                cmdKey = 'D';
                Serial.println("Data Sync Command");
                readFile();
            }
            else if (cmd[i] == 'T' && cmd[i + 1] == '\0')
            { //[Time Command]
                cmdKey = 'T';
                Serial.println("RTC Command"); // Command Format: {'T','\0'}
                rtcFunc();
                pCharacteristic->setValue(timeStamp);
                pCharacteristic->notify();
            }
            else if (cmd[i] == 'R' && cmd[i + 1] == '\0')
            { //[Restart Command]
                cmdKey = 'R';
                Serial.println("Restart Command"); // Command Format: {'R','\0'}
                ESP.restart();
            }
            else if (cmd[i] == 'A' && cmd[i + 3] == '\0')
            {
                Serial.println("Auto Mode Command");
                if (cmd[i + 1] == delm)
                {
                    if (cmd[i + 2] == '1')
                    {
                        autoMode = 1;
                        pref.putBool("auto", autoMode);
                        pCharacteristic->setValue("[AUTO MODE] ON");
                        pCharacteristic->notify();
                    }
                    else if (cmd[i + 2] == '0')
                    {
                        autoMode = 0;
                        pref.putBool("auto", autoMode);
                        pCharacteristic->setValue("[AUTO MODE] OFF");
                        pCharacteristic->notify();
                    }
                    else
                    {
                        Serial.println("Invalid Auto Mode");
                        pCharacteristic->setValue("[Error]Invalid Auto Mode");
                        pCharacteristic->notify();
                    }
                }
                else
                {
                    Serial.println("Invalid Command");
                    pCharacteristic->setValue("[Error]Invalid Command");
                    pCharacteristic->notify();
                }
            }
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

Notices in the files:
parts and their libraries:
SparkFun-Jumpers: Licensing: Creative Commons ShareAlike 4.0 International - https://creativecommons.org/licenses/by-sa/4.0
